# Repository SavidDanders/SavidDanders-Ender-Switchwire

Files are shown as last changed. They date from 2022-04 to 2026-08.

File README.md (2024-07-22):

# SavidDanders-Ender-Switchwire
My mods and configurations for my Ender 3 Pro to Voron Switchwire Conversion.

| Mod | Download | Description | Photo |
|---|---|---|---|
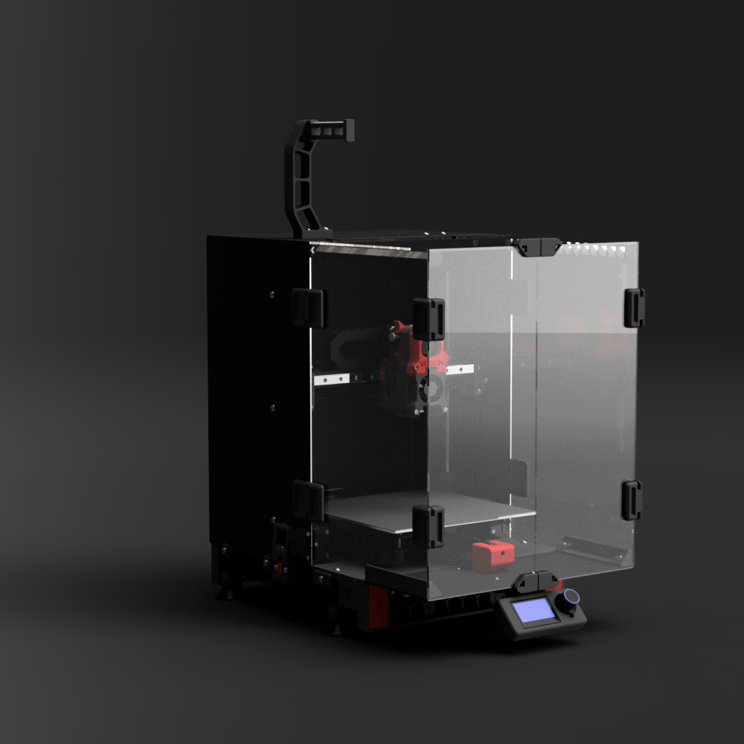
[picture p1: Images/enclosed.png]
Ender 3 to Switchwire Conversion
| boubounokefalos conversion | [Git](https://github.com/boubounokefalos/Ender_SW) | The main conversion for an Ender 3 to Switchwire. This is the starting point where I build off of. | |
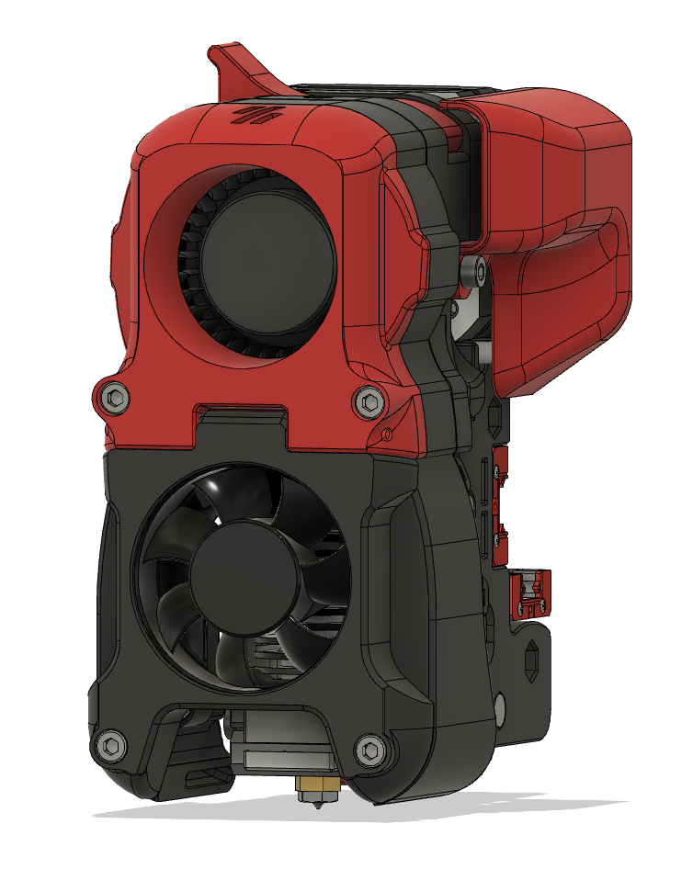
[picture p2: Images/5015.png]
Afterburner 5015 Fan Mod
| Afterburner 5015 Fan Mod | [Git](https://github.com/Greg191134/Voron/tree/master/Afterburner%20Optimisation/5015%20fan%20mod) | The larger cooling fan is better for printing PLA. This requries trimming the 5015 fan a lot to fit in the toolhead. | |
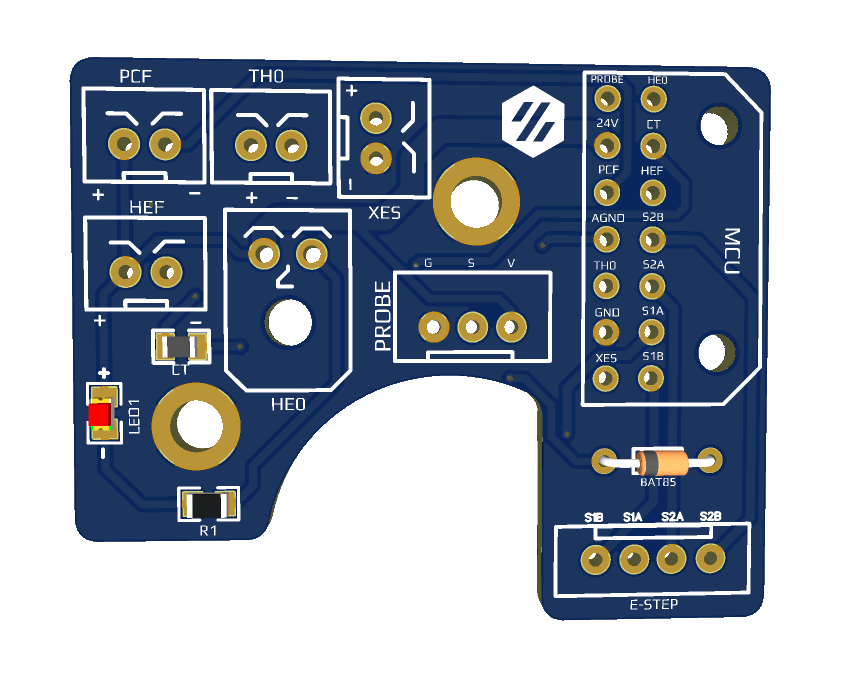
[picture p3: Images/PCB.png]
Afterburner PCB Mod
| Afterburner PCB Toolhead | [Git](https://github.com/VoronDesign/Voron-Hardware/tree/master/Afterburner_Toolhead_PCB) | Mostly a convience mod. Reduces the number of wires needed to run and crimp for the hotend assembly. | |
| Afterburner Microswiss Hotend | [Thingiverse](https://www.thingiverse.com/thing:4826740) | Instead of buying a new hotend I decided to re-use the Trainglelabs Micro-Swiss clone. Since it's all metal it has no issues printing ABS | |
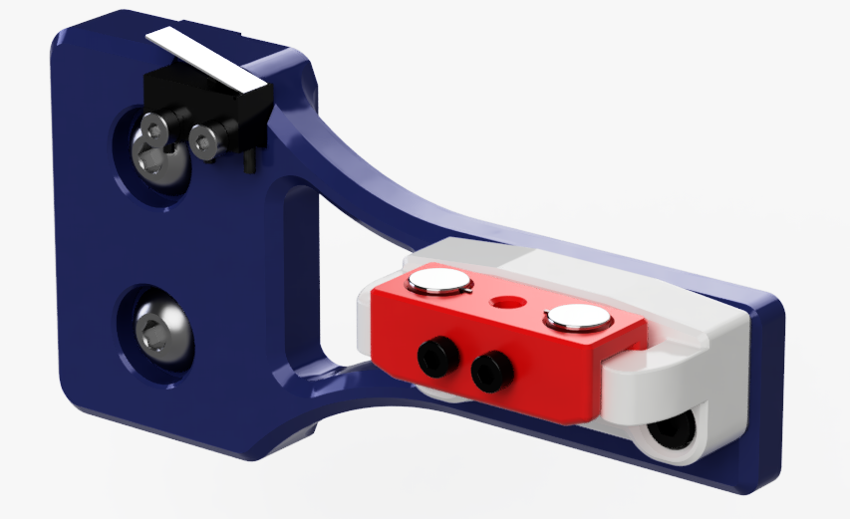
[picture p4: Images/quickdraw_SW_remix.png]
Original Switchwire ABL Probe
| hymness1 Quickdraw ABL Probe  | [Git](https://github.com/VoronDesign/VoronUsers/tree/master/printer_mods/hymness1/Quickdraw_probe_Voron_Switchwire) | I skipped the inductive probe and went straight to Quickdraw. The Quickdraw probe is mechanical so the reading shouldn't change as temps fluctuate. Only downside is losing some build volume on the x-axis since the probe need space to dock. | |
| Mairis Skuja (Iconic FAB) Klicky Dock | [Printables](https://www.printables.com/model/949854-clicky-quickdraw-probe-dock-arm-for-ender-sw-voron) | The standard Quickdraw dock doesn't fit the Ender frame. I use the adjustable dock with heatset arm. | |
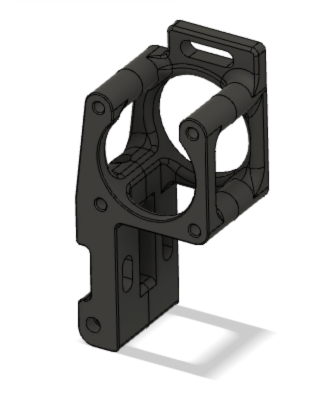
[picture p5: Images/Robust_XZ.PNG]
Robust XZ Motor Mounts
| yenda More Robust Belt Paths  | [Git](https://github.com/VoronDesign/VoronUsers/tree/master/printer_mods/yenda/vsw_more_robust_belt_paths) | I prefer this XZ motor assembly design over the stock ones. | |
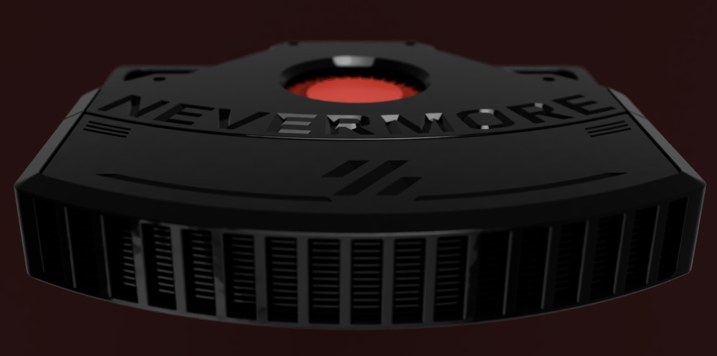
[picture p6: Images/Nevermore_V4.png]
Nevermore V4 Carbon Filter
| Nevermore Micro V4 | [Git](https://github.com/nevermore3d/Nevermore_Micro) | Activated carbon filter to reduce ABS fumes. | |
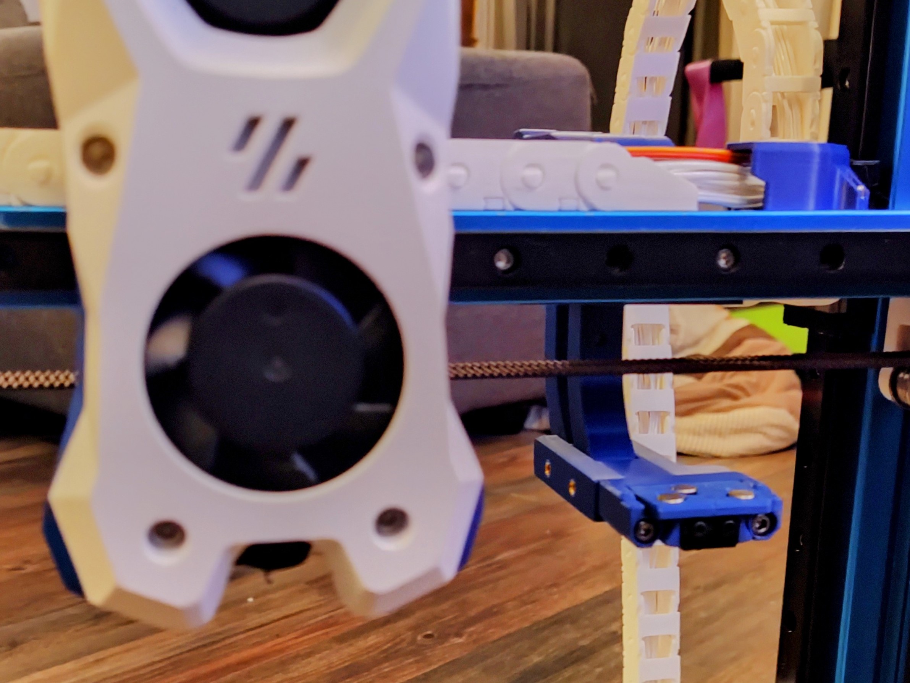
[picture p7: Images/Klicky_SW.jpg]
Klicky Switchwire Probe
| Klicky Probe | [Git](https://github.com/jlas1/Klicky-Probe/tree/main/Printers/Voron/Switchwire) | Replacing the Quickdraw probe with Klicky. This will allow me to take back some space on the X-axis while still using a button switch for accurate bed meshing. | |
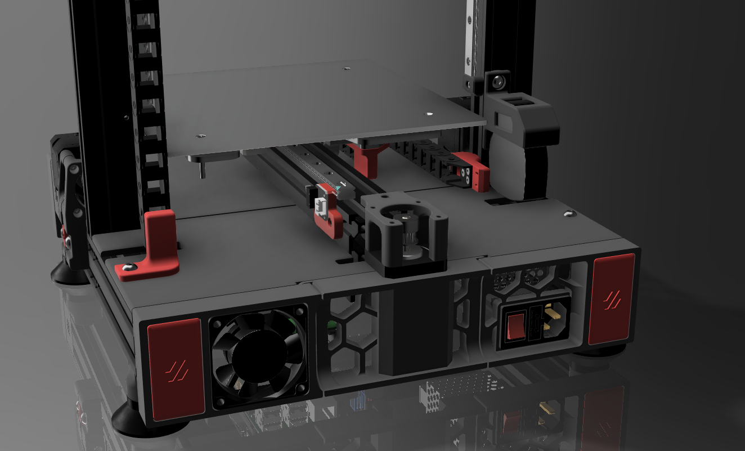
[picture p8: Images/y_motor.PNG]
Beeg Y-Motor Mod
| SavidDanders Beeg Y-Motor | [Git](https://github.com/SavidDanders/SavidDanders-Ender-Switchwire/tree/main/Beeg%20Y-Motor%20Mod) | Overhalls the Y-Axis assembly to allow for larger motors while keeping everything inside the enclosure. | |

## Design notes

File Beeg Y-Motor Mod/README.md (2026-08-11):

# SavidDanders Beeg Y-Motor Mod
## What is it?

This is my mod to allow for a larger Y-axis motor on the boubounokefalos Ender 3 to Voron Switchwire conversion. My goal is to keep the Y-Motor within the bound of the frame to avoid having to make changes to the enclosure in the future. This re-work changes the belt path to match closer to the original Voron Switchwire design. Full credit to [Gizzle](https://github.com/VoronDesign/VoronUsers/tree/master/printer_mods/Gizzle/ender-3_(pro)_switchwire) for the motor mounts. I have used the same motor mounts and idler as their mod just mirrored for clearance.

Beeg Y-Motor Mod

## Why should I do this?

If you are not happy with the speeds and accelerations of the smaller Creality or other motors, this allows for more clearance for a bigger motor. If you don't want to spend the money for 2 linear rails on the Y-Axis this reduces it to 1. If you have lots of friction or binding on the Y-Axis with 2 rails this is for you.

[Speed Test](https://discord.com/channels/460117602945990666/947303252372906014/973366943748866120) with [Nema 17 17HS24-2104S](https://www.omc-stepperonline.com/nema-17-bipolar-1-8deg-65ncm-92oz-in-2-1a-3-36v-42x42x60mm-4-wires-17hs24-2104s)

## How do I do this?

⚠️ Before you start this will involve drilling holes into your Y-Axis carriage! If you are not okay with this or do not have access to a drill do not attempt this mod.

Start by printing out all the parts in the STL folder. I have oriented all the files for optimal printing. Mechanical parts that are going inside the enclosure should be printed in ABS. The grills, decks, and drill tool can be printed from PLA if it makes life easier.

### Drilling the Y-Carriage
Follow the diagram below to align and secure the drill tool. Use 2x M5 bolts and nuts in the open holes to secure the tool in place. Use a drill with M3 or equivalent bit size to drill the remaining 3 holes.

⚠️ Be careful with this process. Have parts properly secured while drilling. I will not be liable for personal or property damages.

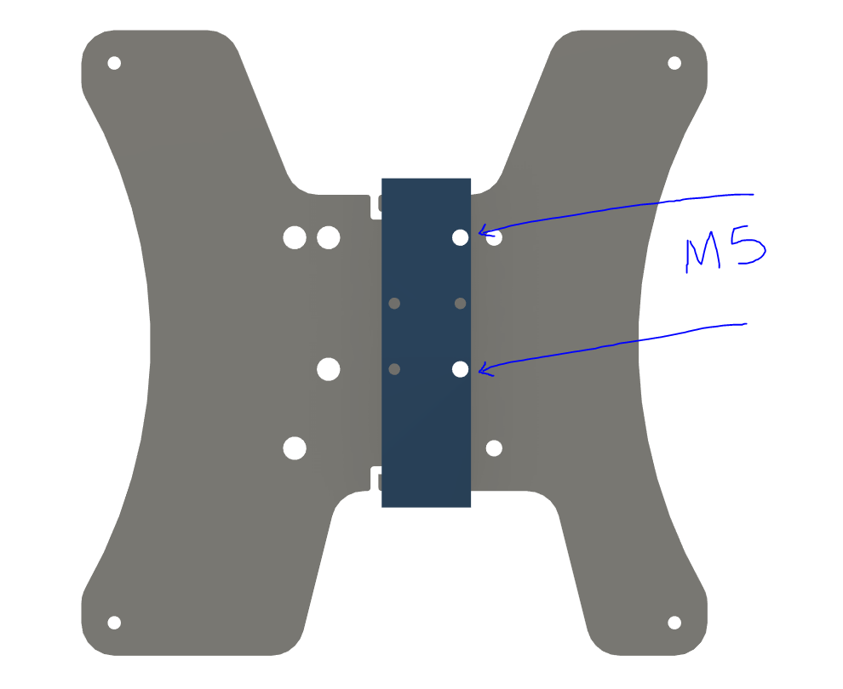
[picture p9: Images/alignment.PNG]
Alignment tool diagram


With the carriage drilled the single MGN12H linear rail can be attached to the top of the Y extrusion. From here you can reference the CAD files for a better idea of how everything is assembled. As of this initial release there is no belt tensioner for the Y-axis. Properly tensioning the Y belt is difficult but not impossible. My method involves having the motor attached, the belt-fed through the belt holder, and clamped. You can then use insert the y_idler_top and use the M5 bolt as leverage to secure the belt. 

## Future changes

This is my passion project, updates may be ~~sporadic or~~ non-existent. With that being said I would like to improve this mod in the future.
* Bill of Materials
* Y-Axis Belt Tensioner
* Updated CAD with all hardware
* Better looking back middle grill

Update 8/2026: I am no longer working on this mod. My E3-PRO VSW uses the [BOM Y Axis from release 2](https://github.com/boubounokefalos/Ender_SW)

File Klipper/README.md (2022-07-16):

# Ender Switchwire Klipper Backup
A lot of macros come from hymness1's configuration with some changes for my printer.

# Slicer Start G-Code
M104 S0
M140 S0
PRINT_START EXTRUDER_TEMP=[first_layer_temperature] BED_TEMP=[first_layer_bed_temperature] DWELL=5
PRIME_LINE

# Slicer End G-Code
G91 ;Relative positioning
G1 E-2 F2700 ;Retract a bit
G1 E-2 Z0.2 F2400 ;Retract and raise Z
G1 X5 Y5 F3000 ;Wipe out
G1 Z10 ;Raise Z more
G90 ;Absolute positioning

G1 X0 Y200
DO_PARK
M106 S0 ;Turn-off fan
M104 S0 ;Turn-off hotend
M140 S0 ;Turn-off bed

M84 X Y E ;Disable all steppers but Z

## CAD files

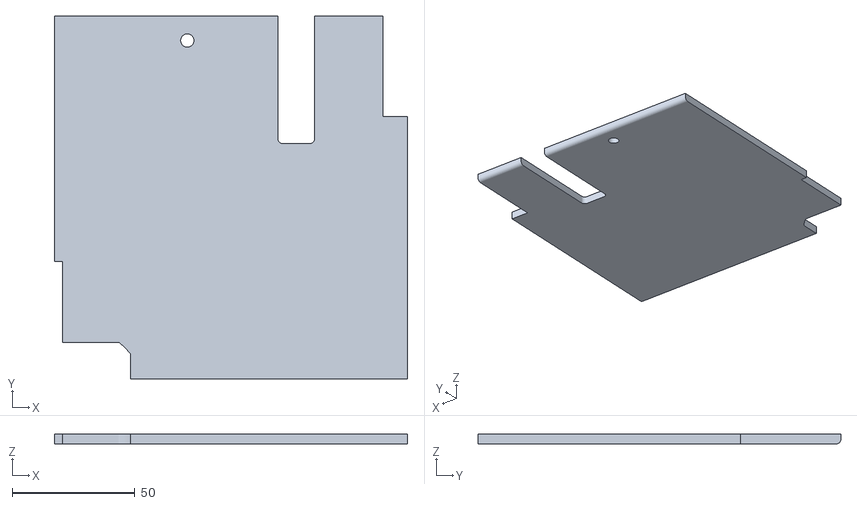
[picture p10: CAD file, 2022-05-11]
Beeg Y-Motor Mod/STL/deck_rear_left.stl
144.0 x 148.0 x 4.00

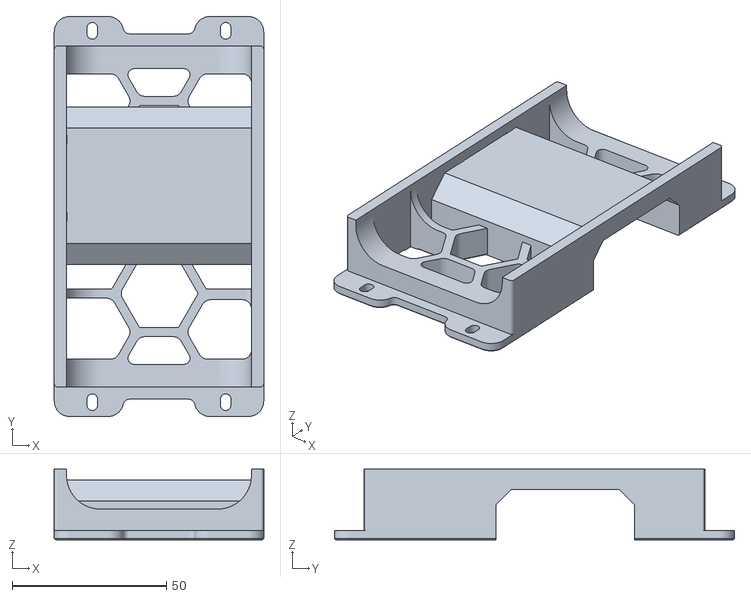
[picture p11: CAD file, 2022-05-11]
Beeg Y-Motor Mod/STL/grill_rear_middle.stl
68.0 x 129.8 x 23.0

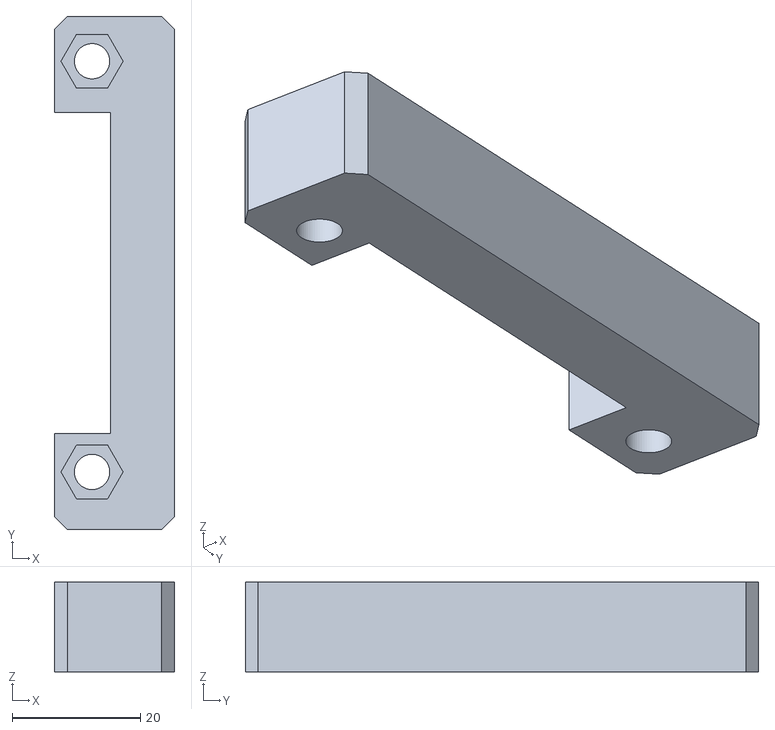
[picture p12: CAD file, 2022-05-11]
Beeg Y-Motor Mod/STL/y_carriage_bumper.stl
18.7 x 80.0 x 14.0

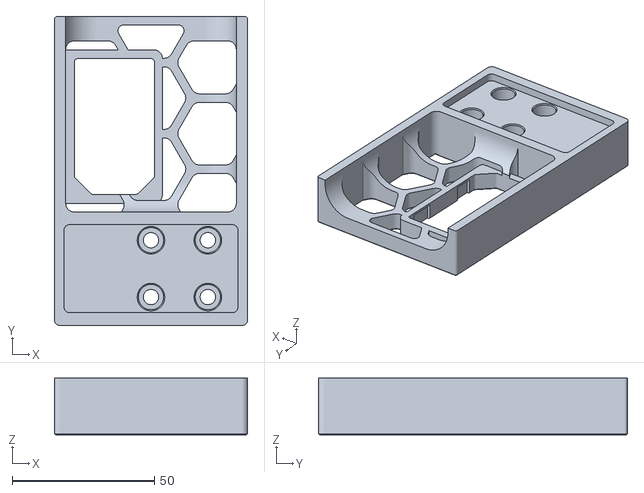
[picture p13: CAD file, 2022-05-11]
Beeg Y-Motor Mod/STL/grill_rear_left.stl
68.0 x 108.7 x 20.0

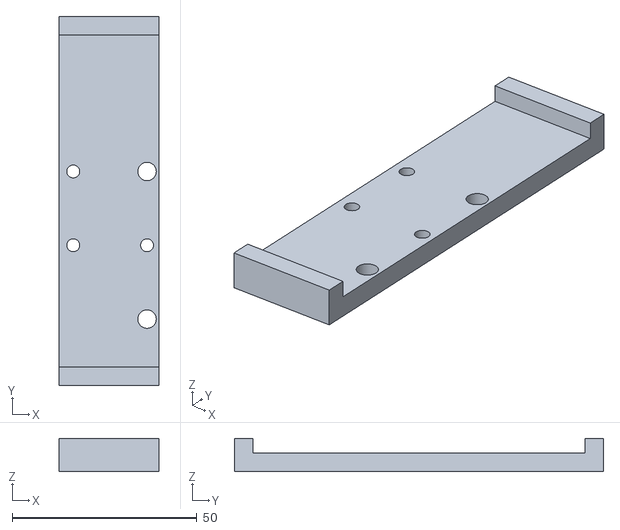
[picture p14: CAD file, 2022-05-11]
Beeg Y-Motor Mod/STL/[tool]_drill_guide.stl
27.1 x 100.0 x 9.00

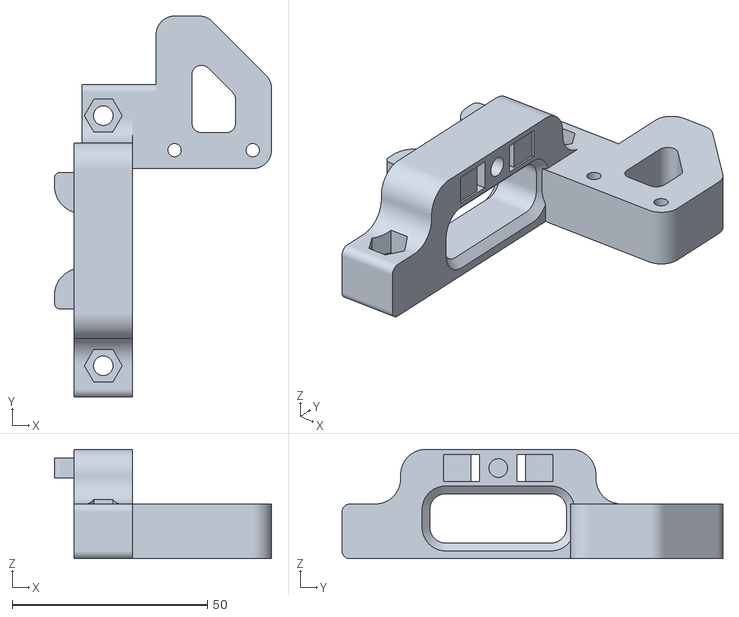
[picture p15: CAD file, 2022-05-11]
Beeg Y-Motor Mod/STL/y_carriage_belt_holder.stl
55.6 x 97.5 x 28.0

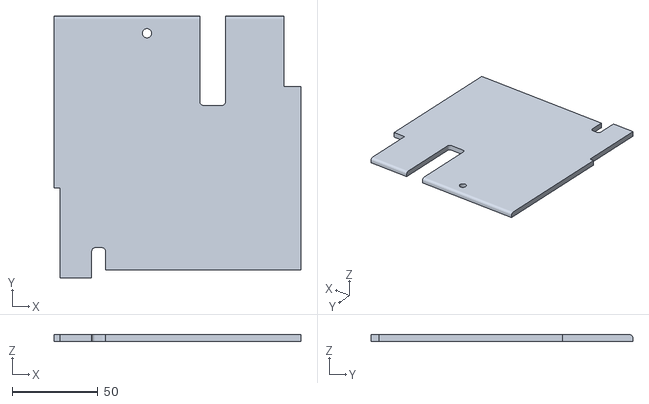
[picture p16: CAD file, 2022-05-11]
Beeg Y-Motor Mod/STL/deck_rear_right.stl
144.0 x 152.6 x 4.00

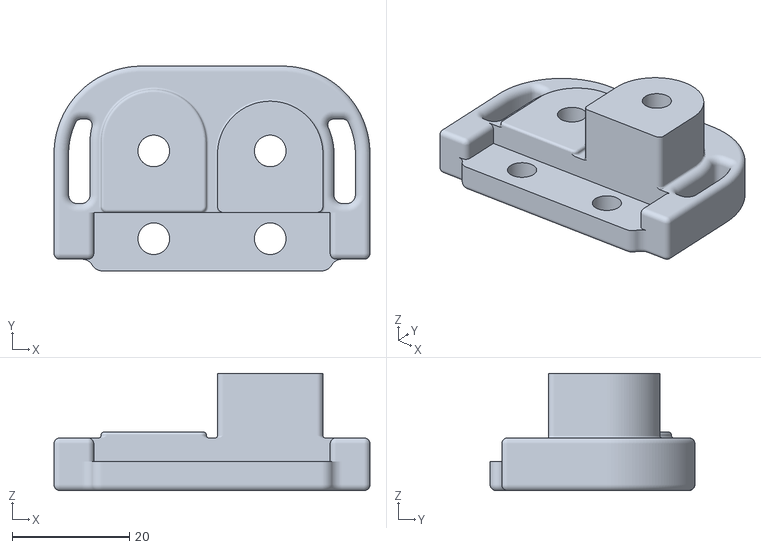
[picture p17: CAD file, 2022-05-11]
Beeg Y-Motor Mod/STL/y_idler_top.stl
54.0 x 35.0 x 20.0

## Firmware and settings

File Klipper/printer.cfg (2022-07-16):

#   Test build configuration for Voron Switchwire / Ender SW conversion with SKR Mini E3 V2.0

#   ————————————————————————————————————————————————
#   Included configuration files
#   ————————————————————————————————————————————————

#[include sb_leds.cfg]
#[include led_macros.cfg]
[include dock_macros.cfg]
[include print_start.cfg]
[include print_end.cfg]
[include kiauh_macros.cfg]

#   ————————————————————————————————————————————————
#   Steppers & TMC2209
#   ————————————————————————————————————————————————

[stepper_x]
step_pin: PB13
dir_pin: PB12
enable_pin: !PB14
microsteps = 16
rotation_distance = 40
endstop_pin: ^PC0
position_endstop: 210
position_max: 210
position_min:0
homing_speed: 150

[tmc2209 stepper_x]
uart_pin: PC11
tx_pin: PC10
uart_address: 0
run_current: 0.6 #Ender Motors
#run_current: 1.1 #E3D High Torque
#hold_current: 0.3
interpolate: true
stealthchop_threshold: 9999

[stepper_y]
step_pin: PB10
dir_pin: !PB2
enable_pin: !PB11
endstop_pin: ^PC1
microsteps = 16
rotation_distance: 40
position_endstop: 0
position_max: 215
position_min: 0
homing_speed: 150

[tmc2209 stepper_y]
uart_pin: PC11
tx_pin: PC10
uart_address: 2
run_current: 1.5
#hold_current: 0.3
interpolate: true
stealthchop_threshold: 9999

[stepper_z]
step_pin: PB0
dir_pin: PC5
enable_pin: !PB1
endstop_pin: ^PC2
endstop_pin: probe:z_virtual_endstop
microsteps = 16
rotation_distance = 40
#position_endstop: 0
position_max: 250
position_min: -10
homing_speed: 20

[tmc2209 stepper_z]
uart_pin: PC11
tx_pin: PC10
uart_address: 1
run_current: 0.6 #Ender Motors
#run_current: 1.1 #E3D High Torque
#hold_current: 0.3
stealthchop_threshold: 9999


[probe]
pin: ^PC14 #E0-Stop Connection on SKR mini E3 V2
#z_offset: 9.400 #Measure per your specific setup [Measured with PROBE_CALIBRATE & Paper test]
x_offset: -1
y_offset: 34.5
speed: 10
samples: 2
samples_tolerance_retries: 4
samples_result: median

[bed_mesh]
speed: 150
horizontal_move_z: 11.5
mesh_min: 0,39.5
mesh_max: 180,220
probe_count: 7
algorithm: bicubic
fade_start: 1
fade_end: 10
fade_target: 0

[screws_tilt_adjust]
screw1: 180,165
screw1_name: Rear right screw
screw2: 180,0
screw2_name: Front right screw
screw3: 15,0
screw3_name: Front left screw
screw4: 15,165
screw4_name: Rear left screw
horizontal_move_z: 15
speed: 250
screw_thread: CW-M3

#   ————————————————————————————————————————————————
#   Extruder
#   ————————————————————————————————————————————————

[extruder]
step_pin: PB3
dir_pin: PB4
enable_pin: !PD2
heater_pin: PC8
sensor_pin: PA0
microsteps: 128
rotation_distance: 22.6789511
gear_ratio: 50:17
nozzle_diameter: 0.400
filament_diameter: 1.750
sensor_type: EPCOS 100K B57560G104F
min_temp: 5
max_temp: 300
#control = pid
#pid_kp = 18.973
#pid_ki = 0.771
#pid_kd = 116.683
min_extrude_temp: 200
max_extrude_only_distance: 250.0
max_extrude_cross_section: 2
#pressure_advance: 0.07905 #Polymaker ABS 0.4mm Nozzle
pressure_advance: 0.07 #ESUN ABS+ 0.4mm Nozzle

[tmc2209 extruder]
uart_pin: PC11
tx_pin: PC10
uart_address: 3
run_current: 0.55 #orbiter / clockwork
#run_current: 0.55 #orbiter / clockwork
#run_current: 1 #orbiter / clockwork
#hold_current: 0.3 #small TL / Clockwork
interpolate: false
#stealthchop_threshold: 250

#   ————————————————————————————————————————————————
#   Heater bed
#   ————————————————————————————————————————————————

[heater_bed]
heater_pin: PC9
sensor_type: ATC Semitec 104GT-2
sensor_pin: PC3
#control: pid
#pid_Kp: 54.027
#pid_Ki: 0.770
#pid_Kd: 948.182
min_temp: 0
max_temp: 130

#   ————————————————————————————————————————————————
#   Fans
#   ————————————————————————————————————————————————

[controller_fan case_fan_1]
pin: PC7
max_power: 1.0
shutdown_speed: 0.0
kick_start_time: 1.0
idle_timeout: 0
fan_speed: 1.0

[fan]
pin: PC6

#   ————————————————————————————————————————————————
#   MCU
#   ————————————————————————————————————————————————

[mcu]
serial: /dev/ttyAMA0
restart_method: command

[printer]
kinematics: corexz
max_velocity: 650
max_accel: 7000
max_z_velocity: 150
max_z_accel: 1000
square_corner_velocity: 4.0

[virtual_sdcard]
path: ~/gcode_files

[static_digital_output usb_pullup_enable]
pins: !PA14

#######################################
#### Enclosure Temp Sensor Section ####
#######################################
[thermistor chamber_temp]
temperature1: 10
resistance1: 10000
beta: 3950

[temperature_sensor enclosure_temp]
sensor_type: chamber_temp
sensor_pin: PC2
min_temp: 0
max_temp: 100
gcode_id: C

[temperature_sensor raspberry_pi]
sensor_type: temperature_host
min_temp: 10
max_temp: 100

[temperature_sensor mcu_temp]
sensor_type: temperature_mcu
min_temp: 0
max_temp: 100

#   ————————————————————————————————————————————————
#   FYSETC mini12864 LCD Display v2.1
#   ————————————————————————————————————————————————

[board_pins]
aliases:
    # EXP1 header
    EXP1_1=PB5, EXP1_3=PA9,   EXP1_5=PA10, EXP1_7=PB8, EXP1_9=<GND>,
    EXP1_2=PA15, EXP1_4=<RST>, EXP1_6=PB9,  EXP1_8=PB15, EXP1_10=<5V>

#[display]
#   Display
#lcd_type: uc1701
#cs_pin: PB8
#a0_pin: PB15
#rst_pin: PB9
#encoder_pins: ^PA9,^PA10
#click_pin: ^!PB5
#contrast: 63
#spi_software_sclk_pin: PA5
#spi_software_mosi_pin: PA7
#spi_software_miso_pin: PA6

#[neopixel fysetc_mini12864]
#    Controls for Neopixel RGB in mini12864 display
#pin: PA15
#chain_count: 3
#initial_RED: 1.0
#initial_GREEN: 0.0
#initial_BLUE: 0.0
#color_order: RGB

#   ————————————————————————————————————————————————
#   Macros
#   ————————————————————————————————————————————————

[gcode_macro G29]
gcode:
    BED_MESH_CLEAR
    BED_MESH_CALIBRATE

#*# <---------------------- SAVE_CONFIG ---------------------->
#*# DO NOT EDIT THIS BLOCK OR BELOW. The contents are auto-generated.
#*#
#*# [extruder]
#*# control = pid
#*# pid_kp = 33.682
#*# pid_ki = 3.622
#*# pid_kd = 78.311
#*#
#*# [heater_bed]
#*# control = pid
#*# pid_kp = 69.475
#*# pid_ki = 0.896
#*# pid_kd = 1346.953
#*#
#*# [probe]
#*# z_offset = 9.420
#*#
#*# [bed_mesh default]
#*# version = 1
#*# points =
#*# 	  -0.025000, -0.037500, -0.068750, -0.062500, -0.068750, -0.068750, -0.112500
#*# 	  0.025000, -0.000000, -0.006250, -0.012500, -0.031250, -0.025000, -0.056250
#*# 	  0.031250, 0.025000, -0.006250, 0.006250, -0.012500, -0.000000, -0.031250
#*# 	  0.031250, 0.018750, -0.000000, 0.012500, -0.018750, -0.012500, -0.050000
#*# 	  0.043750, 0.018750, -0.006250, -0.000000, -0.012500, -0.012500, -0.043750
#*# 	  -0.000000, -0.025000, -0.043750, -0.031250, -0.031250, -0.037500, -0.050000
#*# 	  -0.043750, -0.075000, -0.093750, -0.075000, -0.062500, -0.062500, -0.093750
#*# tension = 0.2
#*# min_x = 0.0
#*# algo = bicubic
#*# y_count = 7
#*# mesh_y_pps = 2
#*# min_y = 39.5
#*# x_count = 7
#*# max_y = 219.97
#*# mesh_x_pps = 2
#*# max_x = 180.0

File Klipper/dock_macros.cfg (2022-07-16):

###############################################################################
####                          Edit this section                            ####
###############################################################################

[gcode_macro GlobalVariables]

# Location of the probe when docked.
variable_dock_x: 210       # X location
variable_dock_z: 21      # Z location

# What other way can you home the Z-Axis (prior to attaching the probe)? Use 3 ONLY if
# you can have the X-carriage and toolhead clear of the bed when the gantry is resting
# on the lower Z end blocks with the bed pushed all the way to the rear
variable_initial_homing: 3  # 1(none/probe only), 2(Z-max microswitch endstop), 3(Z-min microswitch endstop)

variable_dock_x_offset: 27  # The distance to move along x when docking/undocking the probe from the dock
variable_dock_z_offset: 10  # The distance to move along z when attaching/detaching the probe to/from the toolhead

# Travel and Dock speeds
variable_travel_speed: 9000 # Travel speed
variable_dock_speed: 6000   # Docking maneuvers speed

gcode:

###############################################################################
####                     Do not change the lines below                     ####
###############################################################################

[homing_override]
axes: xyz
gcode:
    SET_GCODE_OFFSET Z=0
    query_probe
    do_Home

[gcode_macro do_Home]
gcode:
    GlobalVariables
    {% set dock_x = printer["gcode_macro GlobalVariables"].dock_x %}
    {% set dock_z = printer["gcode_macro GlobalVariables"].dock_z %}
    {% set dock_z_offset = printer["gcode_macro GlobalVariables"].dock_z_offset %}
    {% set travel_speed = printer["gcode_macro GlobalVariables"].travel_speed %}
    {% set initial_homing = printer["gcode_macro GlobalVariables"].initial_homing %}

    {% if printer.toolhead.homed_axes == 'xyz' %}
        G90
        G0 Z{ dock_z + dock_z_offset } F{ travel_speed }

        G28 X0 Y0

        Attach_probe
        PROBE_HOMING

	{% else %}
        SET_KINEMATIC_POSITION X={ dock_x } Z=0
        G90
        G0 Z{ dock_z + dock_z_offset } F{ travel_speed }

        G28 X0 Y0

        {% if printer.probe.last_query == 0 %}
            PROBE_HOMING
        {% endif %}

        {% if printer.probe.last_query == 1 %}
            {% if initial_homing == 1 %}
                RESPOND TYPE=error MSG="Please attach probe"
                M117 Please attach probe
            {% endif %}
            {% if initial_homing == 2 %}
                SENSORLESS_HOMING
            {% endif %}
            {% if initial_homing == 3 %}
                PROBELESS_HOMING
            {% endif %}
	        {% if initial_homing == 4 %}
                PROBELESS_HOMING
            {% endif %}
        {% endif %}
    {% endif %}

[gcode_macro PROBELESS_HOMING]
gcode:
    GlobalVariables
    {% set dock_z = printer["gcode_macro GlobalVariables"].dock_z %}
    {% set dock_z_offset = printer["gcode_macro GlobalVariables"].dock_z_offset %}
    {% set travel_speed = printer["gcode_macro GlobalVariables"].travel_speed %}
    {% set home_x = printer.configfile.config.stepper_x.position_max|int %}
    {% set home_y = printer.configfile.config.stepper_y.position_max|int %}
    {% set probe_y_offset = printer.configfile.settings.probe.y_offset %}
    {% set y_min = printer.configfile.settings.stepper_y.position_min %}
    {% set initial_homing = printer["gcode_macro GlobalVariables"].initial_homing %}

    {% if initial_homing == 3 %}
        G0 X{ home_x / 2 } Y{ y_min + 5 } F{ travel_speed }
    {% endif %}

    {% if initial_homing == 4 %}
        G0 X{ home_x / 2 } Y{ home_y / 2 - probe_y_offset } F{ travel_speed }
    {% endif %}

    G28 Z0
    G0 Z{dock_z + dock_z_offset } F{ travel_speed }
    Attach_probe
    Adjust_Z

[gcode_macro PROBE_HOMING]
gcode:
    Adjust_Z

[gcode_macro Adjust_Z]
gcode:
    GlobalVariables
    {% set travel_speed = printer["gcode_macro GlobalVariables"].travel_speed %}
    {% set home_x = printer.configfile.config.stepper_x.position_max|int %}
    {% set home_y = printer.configfile.config.stepper_y.position_max|int %}
    {% set probe_y_offset = printer.configfile.settings.probe.y_offset %}
    {% set z_max = printer.configfile.config.stepper_z.position_max %}
    {% set probe_offset_z = printer.configfile.config.probe.z_offset|float %}

    G0 X{ home_x / 2 } Y{ home_y / 2 - probe_y_offset } F { travel_speed }
    SET_KINEMATIC_POSITION Z={ z_max }
    PROBE PROBE_SPEED=10
    SET_KINEMATIC_POSITION Z={probe_offset_z}
    G91
    G0 Z2 F{ travel_speed }
    G90
    PROBE PROBE_SPEED=5
    SET_KINEMATIC_POSITION Z={probe_offset_z}
    G0 Z{ probe_offset_z + 3 } F{ travel_speed }

[gcode_macro Dock_probe]
gcode:
    query_probe
    do_Dock

[gcode_macro do_Dock]
gcode:
    {% if printer.probe.last_query == 1 %}
        RESPOND PREFIX= MSG="Probe is already docked!"
        M117 Probe is already docked!

    {% else %}
	    GlobalVariables
        {% set dock_x = printer["gcode_macro GlobalVariables"].dock_x %}
        {% set dock_z = printer["gcode_macro GlobalVariables"].dock_z %}
        {% set home_y = printer.configfile.config.stepper_y.position_max|int %}
        {% set dock_x_offset = printer["gcode_macro GlobalVariables"].dock_x_offset %}
        {% set dock_z_offset = printer["gcode_macro GlobalVariables"].dock_z_offset %}
        {% set travel_speed = printer["gcode_macro GlobalVariables"].travel_speed %}
        {% set dock_speed = printer["gcode_macro GlobalVariables"].dock_speed %}
        {% set probe_y_offset = printer.configfile.settings.probe.y_offset %}

        {% if printer.toolhead.homed_axes != 'xyz' %}
	        G28	# Home All Axes
	    {% endif %}

        G90
        G0 Z{ dock_z + dock_z_offset } F{ travel_speed }
        G0 X{ dock_x } Y{ home_y / 2 - probe_y_offset } F{ dock_speed }
        G0 Z{ dock_z } F{ dock_speed }
        G0 X{ dock_x - dock_x_offset } Y{ home_y / 2 - probe_y_offset } F{ dock_speed }
        G0 Z{ dock_z } F{ travel_speed }
    {% endif %}

    verify_Docking

[gcode_macro verify_Docking]
gcode:
    query_probe
    safe_Dock

[gcode_macro safe_Dock]
gcode:
    {% if printer.probe.last_query != 1 %}
        M112
    {% endif %}

[gcode_macro Attach_probe]
gcode:
    query_probe
    do_Attach

[gcode_macro do_Attach]
gcode:
    {% if printer.probe.last_query == 0 %}
        RESPOND PREFIX= MSG="Probe is already attached!"
        M117 Probe is already attached!

    {% else %}
        GlobalVariables
        {% set dock_x = printer["gcode_macro GlobalVariables"].dock_x %}
        {% set dock_z = printer["gcode_macro GlobalVariables"].dock_z %}
        {% set dock_x_offset = printer["gcode_macro GlobalVariables"].dock_x_offset %}
        {% set dock_z_offset = printer["gcode_macro GlobalVariables"].dock_z_offset %}
        {% set travel_speed = printer["gcode_macro GlobalVariables"].travel_speed %}
        {% set dock_speed = printer["gcode_macro GlobalVariables"].dock_speed %}
        {% set home_y = printer.configfile.config.stepper_y.position_max|int %}
        {% set probe_y_offset = printer.configfile.settings.probe.y_offset %}

        {% if printer.toolhead.homed_axes != 'xyz' %}
	        G28	# Home All Axes
	    {% endif %}

        G90
        G0 X{ dock_x - dock_x_offset } F{ travel_speed }
        G0 Z{ dock_z } F{ travel_speed }
        G0 X{ dock_x } Y{ (home_y / 2) - probe_y_offset } F{ dock_speed }
        G0 Z{ dock_z + dock_z_offset } F{ dock_speed }
        G0 X{ dock_x - dock_x_offset } Y{ home_y / 2 - probe_y_offset } F{ dock_speed }
        G0 Z{ dock_z } F{ travel_speed }
    {% endif %}

[gcode_macro Park_toolhead]
gcode:
    query_probe
    do_Park
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

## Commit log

2022-05-11 Added Beeg Y-Motor Mod
    Initial release of the "Beeg Y-Motor Mod"
    [[tool]_drill_guide.stl, deck_rear_left.stl, deck_rear_right.stl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]
2022-05-11 Added Beeg Y-Motor mod
2022-05-12 Beeg Y-Axis Readme
2022-07-16 Added Klipper Backup
    Klipper config backup
    [dock_macros.cfg, fluidd.cfg, kiauh_macros.cfg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]
2024-07-21 Update README.md
    Link change for Quickdraw arm for Ender SW
